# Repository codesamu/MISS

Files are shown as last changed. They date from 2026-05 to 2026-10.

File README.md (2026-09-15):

<div align="center">

# 🗑️ MISS
**An AI-Powered Multi Item Sorting System**






*A Diploma Thesis by **Fronthaler** and **Glatz***

<p align="center">
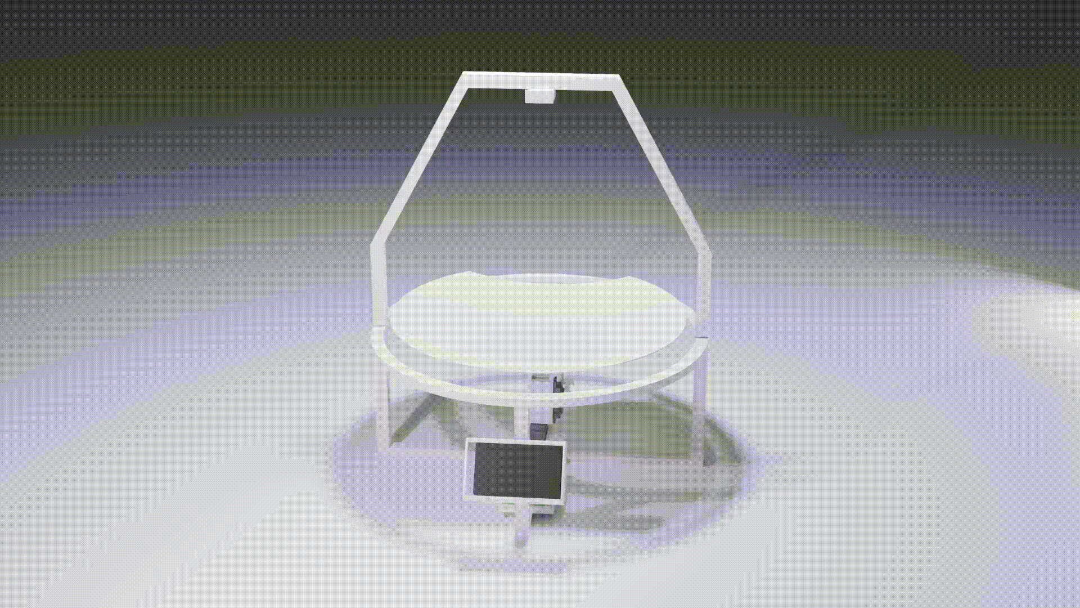
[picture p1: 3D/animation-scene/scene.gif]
MISS Sorting System Animation
  
</p>

</div>

---

## 📝 Overview
MISS (Multi Item Sorting System) is an intelligent waste sorting system designed to automate the process of recycling. By combining computer vision with custom hardware, the system identifies waste types and sorts them accordingly using servos.

## 🚀 Key Features
- **🤖 AI Detection**: Uses YOLO (You Only Look Once) to classify waste in real-time.
- **🖥️ Custom GUI**: A dedicated interface for monitoring camera feeds and system status.
- **⚙️ Hardware Control**: Custom PCB design and servo motor integration for physical sorting.
- **📦 3D Design**: Fully integrated mechanical structure designed for 3D printing.

## 📂 Project Structure
- `3D/`: CAD files, Blender scene, and print-ready STL/3MF files for the physical bin structure.
- `YOLO/`: YOLO model training and detection scripts.
- `capture-photos/`: Scripts for capturing training images from the camera.
- `display-cam-gui/`: Python-based GUI for the system display and camera feed.
- `pcb/`: PCB schematic and layout files for the electronics.
- `servo-test/`: Hardware testing scripts for the sorting mechanisms.
- `Doku-IMG/`: Diagrams and images used in the thesis documentation.

## 🛠️ Tech Stack
- **Languages**: Python
- **AI Framework**: Ultralytics YOLO
- **Hardware**: Custom PCBs, Servo Motors, Raspberry Pi, Camera Module
- **3D Design**: FreeCAD, Blender (for animation renders)

## 📄 Documentation
The complete diploma thesis is included as `Diplomarbeit.docx` in the repository root.

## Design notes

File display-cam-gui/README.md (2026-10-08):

# Live-Erkennung

Im Projektordner einmal einrichten (Systempakete fuer das Display mitverwenden):

```bash
python3 -m venv --system-site-packages .venv
.venv/bin/python -m pip install -r display-cam-gui/requirements.txt
```

Direkt starten:

```bash
.venv/bin/python display-cam-gui/live-detection.py
```

Oder im Dashboard **Live-Erkennung** antippen. Beenden mit dem roten
Touch-Button unten rechts oder Strg+C. Andere Kamera-Apps vorher beenden.

Das Programm zeigt den rpicam-vid-Kamerastream auf dem ST7796-LCD (480x320).
Es verarbeitet immer das neueste verfuegbare Bild und zeichnet Ergebnisse
auf genau dieses Bild. Die Bildrate haengt von der Inferenzzeit ab; waehrend
einer Vorhersage bleibt das zuletzt ausgewertete Bild sichtbar.
Das volle 4:3-Kamerabild bleibt mit schwarzen Raendern erhalten.
Die Kamera laeuft mit 30 FPS; die KI verarbeitet davon nur die jeweils neuesten
Bilder. Die FPS-Anzeige unten misst die Geschwindigkeit der Modellauswertung.

Ohne Argument erscheint zuerst eine **Modellauswahl auf dem Touchdisplay**.
Sie zeigt `YOLO/pet.pt` und die Detection-`best.pt` aus `YOLO/runs/`
beziehungsweise `runs/detect/`, neueste zuerst. Jeder Eintrag zeigt den Namen
des Trainingslaufs. Mit **Weiter/Zurueck** blaettern und den gewuenschten Lauf
antippen. **Abbrechen** kehrt ohne Kamerastart zurueck. Das gilt auch beim
Start aus dem Dashboard. Auf dem Raspberry Pi muessen die gewuenschten
Laufordner mit `train/weights/best.pt` vorhanden sein. Die alten Modelle unter
`runs/classify/` werden absichtlich nicht mehr geladen: Eine Bildklassifikation
kann keine Objektposition und damit keine Bounding Box liefern. Fehlt ein
trainierter Detektor, beendet sich die Anwendung mit einer klaren Meldung.

Bounding Boxes, Klassenname und Confidence werden direkt auf das ausgewertete
Kamerabild gezeichnet. Klassennamen werden aus dem Modell gelesen, etwa
`aluminum-can` und `plastic-bottle`; auch alte PET-Modelle funktionieren.
Jede Klasse hat eine eigene Farbe (die Palette wiederholt sich ab fuenf Klassen).
Mehrere Klassen koennen gleichzeitig erkannt werden. Der Status oben links
wird **pro Klasse getrennt** stabilisiert: Zwei Frames hintereinander muessen mindestens
60 % erreichen. Eine aktive Erkennung bleibt bis zu vier schwache Frames
erhalten; auch die Halteschwelle liegt bei 60 %. Dadurch
springt die Anzeige bei einzelnen unsicheren Frames nicht mehr sofort zwischen
erkannt und nicht erkannt. Ohne aktive Klasse steht dort **Kein Objekt erkannt**.
Mehrere erkannte Klassen erhalten eigene Statuszeilen. Ab fuenf Klassen werden
weitere zusammengefasst; Boxen werden weiterhin fuer alle Klassen gezeichnet. API:
[Ultralytics Predict](https://docs.ultralytics.com/modes/predict/).

Modelle auflisten bzw. einen Run explizit auswaehlen:

```bash
.venv/bin/python display-cam-gui/live-detection.py --list-models
.venv/bin/python display-cam-gui/live-detection.py --model YOLO/pet.pt
.venv/bin/python display-cam-gui/live-detection.py --model YOLO/runs/pet_jhp02naa/train/weights/best.pt
```

`--model` ueberspringt die Touch-Auswahl und akzeptiert auch mehrere Pfade, die nacheinander auf demselben Bild
ausgewertet werden. Das kostet entsprechend mehr Rechenzeit.
Mit `--conf 0.6` die Einschaltschwelle und mit `--keep-conf 0.35` die niedrigere
Halteschwelle ändern. `--confirm-frames` und `--release-frames` steuern die
zeitliche Entprellung. Mit `--imgsz 320` kann die Inferenzgröße verkleinert
werden (Standard: 640); das ist schneller, kann aber Erkennungsqualität kosten.
Fuer einen kurzen Hardwaretest: `--max-frames 10`.

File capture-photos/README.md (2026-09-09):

# Automatische Fotoaufnahme

Das Programm zeigt das aktuelle Kamerabild auf dem 480x320-Touchdisplay an und
speichert alle fuenf Sekunden ein Foto. Die Aufnahme endet, sobald auf dem
Display **STOP** gedrueckt wird.

## Start

Im Projektordner ausfuehren:

```bash
python3 glatz/main.py
```

Vor dem Start muss die bisherige Kamera-App beziehungsweise das Dashboard
vollstaendig beendet sein, da Kamera, Display und Touch nicht von zwei
Programmen gleichzeitig verwendet werden koennen.

Die JPEG-Bilder werden standardmaessig unter `glatz/photos/` abgelegt. Ihre
Dateinamen enthalten Datum und Uhrzeit, zum Beispiel
`muell_20260901_143012_123.jpg`.

Optional lassen sich Zielordner und Intervall aendern:

```bash
python3 glatz/main.py --output-dir /pfad/zu/fotos --interval 5
```

Die Kamera wird fest im 4:3-Modus 1296x972 betrieben. Bei der verbauten OV5647
verwendet dieser Modus den kompletten 2592x1944-Sensorbereich und damit das volle
Sichtfeld. Die Vorschau wird mit schwarzen Seitenraendern eingepasst, damit auch
auf dem 16:9-Bildbereich des Displays nichts abgeschnitten wird.

Das Programm verwendet die bereits im Projekt vorhandenen Display- und
Touch-Treiber aus `display-cam-gui/`. Labeling oder Klassifizierung findet nicht
statt.

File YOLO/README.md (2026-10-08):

# Plastikflaschen und Aludosen trainieren

## Neuen Datensatz wieder zusammenfuehren

Wenn der COCO-Export bereits in `dataset/train`, `dataset/valid` (oder `val`)
und `dataset/test` aufgeteilt ist, im Ordner `YOLO` ausfuehren:

```powershell
python merge_dataset.py
```

Das Programm kopiert alle Bilder nach `dataset/PET` und erstellt dort eine
gemeinsame `_annotations.coco.json`. Bild- und Markierungs-IDs werden eindeutig
neu vergeben; die Zuordnung der Markierungen zu ihren Bildern bleibt erhalten.
Dateinamen bekommen den bisherigen Split als Praefix, etwa `train_bild.jpg`.
Boxen, Klassen, Lizenzen und weitere Metadaten bleiben erhalten.

Der neue Export enthaelt 1741 Bilder und 4478 Markierungen fuer Plastikflaschen
(`plastic-bottle`) und Aludosen (` aluminum-can`). Der Zielordner heisst wie
bisher `PET`, enthaelt aber **beide Klassen**. Die urspruenglichen Teilmengen
werden nicht geloescht. Ein vorhandener Zielordner wird nicht ueberschrieben.
Das Skript benoetigt nur Python, keine zusaetzlichen Bibliotheken.

Andere Ordner lassen sich so angeben:

```powershell
python merge_dataset.py --source "pfad/zum/export" --output "pfad/zum/gesamt"
```

Die Zusammenfuehrung hebt die bisherige Trennung der Testdaten auf. Ein spaeterer
neuer Split ist deshalb eine neue Versuchsaufteilung.

## Training starten

Im Terminal im Ordner `YOLO` ausfuehren:

```powershell
python -m pip install -r requirements.txt
python train.py
```

Das Skript liest `dataset/PET/_annotations.coco.json`, wandelt die Boxen ins
YOLO-Format um und teilt die Bilder reproduzierbar in 80 % Training,
10 % Validierung und 10 % Test. Anschliessend trainiert es YOLO26n fuer
30 Epochen und wertet das beste Modell auf den Testbildern aus.
Beim ersten Training wird das vortrainierte Modell heruntergeladen.

Das fertige Modell liegt unter `YOLO/pet.pt` (wird beim naechsten Training
ersetzt). Jeder Aufruf legt einen eigenen Ordner unter `YOLO/runs/` fuer
Datenkopien und Ergebnisse an. Die Originaldaten bleiben erhalten.
Der Modellname `pet.pt` bleibt aus Kompatibilitaetsgruenden bestehen;
das neu trainierte Modell erkennt beide Klassen.

Optional:

```powershell
python train.py --epochs 50
python train.py --split-only
```

`--split-only` funktioniert auch ohne installierte Trainingsbibliotheken.

Ein Bild mit dem trainierten Modell pruefen:

```powershell
yolo predict model=pet.pt source="pfad/zum/bild.jpg" save=True
```

Training und Auswertung verwenden die [Ultralytics-API](https://docs.ultralytics.com/tasks/detect/).

## Dataset und Vorbereitung

Das zusammengefuehrte Dataset enthaelt 1741 Bilder und 4478 Markierungen.
Die Markierungen stehen im COCO-Format in `_annotations.coco.json`.
Das Training uebernimmt automatisch alle Klassen mit Markierungen und vergibt
fortlaufende YOLO-Klassen-IDs. Leerzeichen am Rand der Klassennamen werden entfernt:

| COCO-ID | YOLO-ID | Klasse |
| --- | --- | --- |
| 1 | 0 | `aluminum-can` (Aludose) |
| 2 | 1 | `plastic-bottle` (Plastikflasche) |

Die unbenutzte Oberkategorie `smartbin` wird nicht als Erkennungsklasse trainiert.

Eine COCO-Box beschreibt `x, y, Breite, Hoehe` in Pixeln, wobei `x, y` die
linke obere Ecke angeben. Eine YOLO-Labelzeile enthaelt dagegen:

```text
Klasse Mittelpunkt_X Mittelpunkt_Y Breite Hoehe
```

Alle vier Koordinaten werden durch die jeweilige Bildbreite bzw. Bildhoehe
geteilt. Sie liegen damit zwischen 0 und 1. Fuer jedes markierte Objekt entsteht
eine Zeile; Bilder ohne Markierung erhalten eine leere Labeldatei.

Die Bilder werden nach ID sortiert und mit Seed 42 gemischt. Beim aktuellen
Dataset entstehen 1392 Trainingsbilder, 174 Validierungsbilder und 175 Testbilder.
Der Rundungsrest geht in die Testmenge. Jedes Bild gehoert genau einer Menge an:

| Teilmenge | Verwendung |
| --- | --- |
| Training | Anpassung der Modellgewichte |
| Validierung | Kontrolle nach den Epochen und Auswahl des besten Modells |
| Test | Abschliessende Auswertung des besten Modells auf zurueckgehaltenen Bildern |

Bei unveraenderten Quelldaten bleibt die Aufteilung bei jedem Aufruf gleich.
Das Training selbst kann je nach Hardware und Bibliotheksversion leicht
unterschiedliche Ergebnisse liefern.

## Trainingseinstellungen

| Einstellung | Wert | Bedeutung |
| --- | --- | --- |
| Modell | `yolo26n.pt` | Kleines vortrainiertes Modell als Ausgangspunkt |
| Epochen | 30 | Angeforderte Durchlaeufe durch die Trainingsdaten; mit `--epochs` aenderbar |
| Bildgroesse | 640 | Zielgroesse fuer die Bildaufbereitung; Originaldateien bleiben unveraendert |
| Batch | 8 | Bilder pro Trainingsschritt |
| Workers | 0 | Laden der Daten im Hauptprozess, einfach unter Windows |
| Seed | 42 | Zufallsstartwert fuer Split und Training |
| Geraet | automatisch | Ultralytics waehlt das verfuegbare Geraet |

Weitere Einstellungen wie Optimierer, Lernrate, Datenaugmentation und vorzeitiges
Beenden verwenden die Standardwerte der installierten Ultralytics-Version.
Die konkret aufgeloesten Werte werden in `train/args.yaml` gespeichert.
Die tatsaechlich abgeschlossenen Epochen stehen in `train/results.csv`.
Auf der CPU kann das Training deutlich laenger dauern als auf einer GPU.

Nach dem Training wird `weights/best.pt` als `YOLO/pet.pt` kopiert und auf der
Testmenge ausgewertet. `best.pt` ist das anhand der Validierung ausgewaehlte
Modell; `last.pt` enthaelt den zuletzt gespeicherten Trainingsstand.

## Automatische Dokumentation

Jeder Lauf erhaelt unter `YOLO/runs/pet_.../` einen eigenen Ordner:

```text
pet_.../
  bericht.md           Zusammenfassung mit Einstellungen, Laufzeit und Metriken
  dataset/
    data.yaml          Dataset-Pfad, Teilmengen und Klassennamen
    images/            Bilder in train/, val/ und test/
    labels/            Passende YOLO-Labels in train/, val/ und test/
  train/
    args.yaml          Vollstaendige Trainingseinstellungen
    results.csv        Verluste und Metriken pro Epoche
    results.png        Diagramme zum Trainingsverlauf
    weights/
      best.pt          Bestes Modell nach Validierung
      last.pt          Zuletzt gespeicherter Trainingsstand
  test/                Diagramme und Beispielbilder der Testauswertung
```

Ultralytics erzeugt zusaetzlich unter anderem Konfusionsmatrizen, Kurven zur
Erkennungsqualitaet und Bilder mit eingezeichneten Vorhersagen. Die genauen
Dateinamen haengen von der installierten Version ab. `bericht.md` wird nach
erfolgreichem Abschluss der Testauswertung geschrieben. Bei `--split-only`
entsteht nur der vorbereitete Dataset-Ordner.

## Ergebnisse verstehen

| Metrik | Bedeutung |
| --- | --- |
| Precision | Welcher Anteil der erkannten Objekte tatsaechlich korrekt ist; hoch bedeutet wenige Fehlalarme |
| Recall | Welcher Anteil der markierten Objekte gefunden wird; hoch bedeutet wenige uebersehene Objekte |
| mAP50 | Erkennungsqualitaet bei mindestens 50 % Ueberlappung (IoU) zwischen vorhergesagter und echter Box |
| mAP50-95 | Mittlere Erkennungsqualitaet ueber IoU-Schwellen von 0,50 bis 0,95; bewertet die Genauigkeit der Boxen strenger |
| Trainings-/Validierungsverlust | Fehlerfunktion beim Lernen bzw. Pruefen; kleinere Werte sind meist besser |

Precision, Recall und mAP liegen zwischen 0 und 1; groessere Werte sind besser.
Sinkender Trainingsverlust bei schlechter werdender Validierung kann auf
Ueberanpassung hinweisen. Zusaetzlich immer einige Vorhersagebilder anschauen:
Werden Flaschen oder Dosen uebersehen, verwechselt, doppelt markiert oder andere Gegenstaende erkannt?

## Grenzen der Auswertung

Der einfache Split mischt einzelne Bilder. Sehr aehnliche Bilder aus derselben
Aufnahmeserie koennen dadurch in verschiedenen Teilmengen landen und Ergebnisse
zu gut erscheinen lassen. Fuer eine belastbare Beurteilung spaeter mit neuen
Aufnahmeserien, anderen Lichtverhaeltnissen und anderen Flaschen und Dosen testen.

Das Modell lernt die Klassen Plastikflasche und Aludose. Fuer den Einsatz im
Smartbin sind auch Testbilder mit anderem Muell und ohne diese Objekte sinnvoll,
um Fehlalarme zu messen.
Die Testmenge sollte fuer die abschliessende Beurteilung dienen; Einstellungen
anhand der Validierung auswaehlen.

Fuer einen nachvollziehbaren Versuch den gesamten Laufordner zusammen mit der
verwendeten Version von `train.py` und den Originaldaten aufbewahren.

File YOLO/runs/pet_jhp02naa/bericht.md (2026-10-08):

# Trainingsbericht Smartbin

- Ultralytics-Version: 8.4.146
- Startmodell: yolo26n.pt (vortrainiert)
- Aufgabe: Objekterkennung
- Klassen: 0 = aluminum-can, 1 = plastic-bottle
- Angeforderte Epochen: 30
- Bildgroesse: 640; Batch: 8; Workers: 0; Seed: 42
- Aufteilung: 80 % Training / 10 % Validierung / 10 % Test
- Laufzeit inklusive Test: 25.6 Minuten
- Dataset-Konfiguration: C:\Users\maxig\OneDrive\Desktop\smartbin\MISS\YOLO\runs\pet_jhp02naa\dataset\data.yaml
- Bestes Modell dieses Laufs: C:\Users\maxig\OneDrive\Desktop\smartbin\MISS\YOLO\runs\pet_jhp02naa\train\weights\best.pt
- Modellkopie: C:\Users\maxig\OneDrive\Desktop\smartbin\MISS\YOLO\pet.pt

## Bilder pro Teilmenge

- train: 1392
- val: 174
- test: 175

## Validierung

| Metrik | Wert |
| --- | ---: |
| metrics/precision(B) | 0.9572 |
| metrics/recall(B) | 0.9214 |
| metrics/mAP50(B) | 0.9708 |
| metrics/mAP50-95(B) | 0.8477 |
| fitness | 0.8477 |

## Test

| Metrik | Wert |
| --- | ---: |
| metrics/precision(B) | 0.9346 |
| metrics/recall(B) | 0.9260 |
| metrics/mAP50(B) | 0.9615 |
| metrics/mAP50-95(B) | 0.8393 |
| fitness | 0.8393 |

## Detaildateien

- `train/args.yaml`: alle tatsaechlich verwendeten Trainingseinstellungen
- `train/results.csv`: Metriken und Verluste pro abgeschlossener Epoche
- `train/results.png`: Verlauf des Trainings
- `train/`: weitere Diagramme und Beispielbilder der Validierung
- `test/`: Diagramme und Beispielbilder der Testauswertung

Erklaerungen und Grenzen der Auswertung stehen in `YOLO/README.md`.

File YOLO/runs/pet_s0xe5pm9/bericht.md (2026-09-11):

# Trainingsbericht PET

- Ultralytics-Version: 8.4.144
- Startmodell: yolo26n.pt (vortrainiert)
- Aufgabe: Objekterkennung; Klasse 0 = PET
- Angeforderte Epochen: 30
- Bildgroesse: 640; Batch: 8; Workers: 0; Seed: 42
- Aufteilung: 80 % Training / 10 % Validierung / 10 % Test
- Laufzeit inklusive Test: 77.4 Minuten
- Dataset-Konfiguration: C:\Users\maxig\OneDrive\Desktop\smartbin\MISS\YOLO\runs\pet_s0xe5pm9\dataset\data.yaml
- Bestes Modell dieses Laufs: C:\Users\maxig\OneDrive\Desktop\smartbin\MISS\YOLO\runs\pet_s0xe5pm9\train\weights\best.pt
- Modellkopie: C:\Users\maxig\OneDrive\Desktop\smartbin\MISS\YOLO\pet.pt

## Bilder pro Teilmenge

- train: 595
- val: 74
- test: 75

## Validierung

| Metrik | Wert |
| --- | ---: |
| metrics/precision(B) | 0.9096 |
| metrics/recall(B) | 0.8746 |
| metrics/mAP50(B) | 0.9559 |
| metrics/mAP50-95(B) | 0.7227 |
| fitness | 0.7227 |

## Test

| Metrik | Wert |
| --- | ---: |
| metrics/precision(B) | 0.8623 |
| metrics/recall(B) | 0.8939 |
| metrics/mAP50(B) | 0.9513 |
| metrics/mAP50-95(B) | 0.7088 |
| fitness | 0.7088 |

## Detaildateien

- `train/args.yaml`: alle tatsaechlich verwendeten Trainingseinstellungen
- `train/results.csv`: Metriken und Verluste pro abgeschlossener Epoche
- `train/results.png`: Verlauf des Trainings
- `train/`: weitere Diagramme und Beispielbilder der Validierung
- `test/`: Diagramme und Beispielbilder der Testauswertung

Erklaerungen und Grenzen der Auswertung stehen in `YOLO/README.md`.

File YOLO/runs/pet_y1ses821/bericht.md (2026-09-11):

# Trainingsbericht PET

- Ultralytics-Version: 8.4.146
- Startmodell: yolo26n.pt (vortrainiert)
- Aufgabe: Objekterkennung; Klasse 0 = PET
- Angeforderte Epochen: 30
- Bildgroesse: 640; Batch: 8; Workers: 0; Seed: 42
- Aufteilung: 80 % Training / 10 % Validierung / 10 % Test
- Laufzeit inklusive Test: 14.9 Minuten
- Dataset-Konfiguration: C:\Users\maxig\OneDrive\Desktop\smartbin\MISS\YOLO\runs\pet_y1ses821\dataset\data.yaml
- Bestes Modell dieses Laufs: C:\Users\maxig\OneDrive\Desktop\smartbin\MISS\YOLO\runs\pet_y1ses821\train\weights\best.pt
- Modellkopie: C:\Users\maxig\OneDrive\Desktop\smartbin\MISS\YOLO\pet.pt

## Bilder pro Teilmenge

- train: 595
- val: 74
- test: 75

## Validierung

| Metrik | Wert |
| --- | ---: |
| metrics/precision(B) | 0.9109 |
| metrics/recall(B) | 0.8869 |
| metrics/mAP50(B) | 0.9572 |
| metrics/mAP50-95(B) | 0.7236 |
| fitness | 0.7236 |

## Test

| Metrik | Wert |
| --- | ---: |
| metrics/precision(B) | 0.8858 |
| metrics/recall(B) | 0.8575 |
| metrics/mAP50(B) | 0.9467 |
| metrics/mAP50-95(B) | 0.7031 |
| fitness | 0.7031 |

## Detaildateien

- `train/args.yaml`: alle tatsaechlich verwendeten Trainingseinstellungen
- `train/results.csv`: Metriken und Verluste pro abgeschlossener Epoche
- `train/results.png`: Verlauf des Trainings
- `train/`: weitere Diagramme und Beispielbilder der Validierung
- `test/`: Diagramme und Beispielbilder der Testauswertung

Erklaerungen und Grenzen der Auswertung stehen in `YOLO/README.md`.

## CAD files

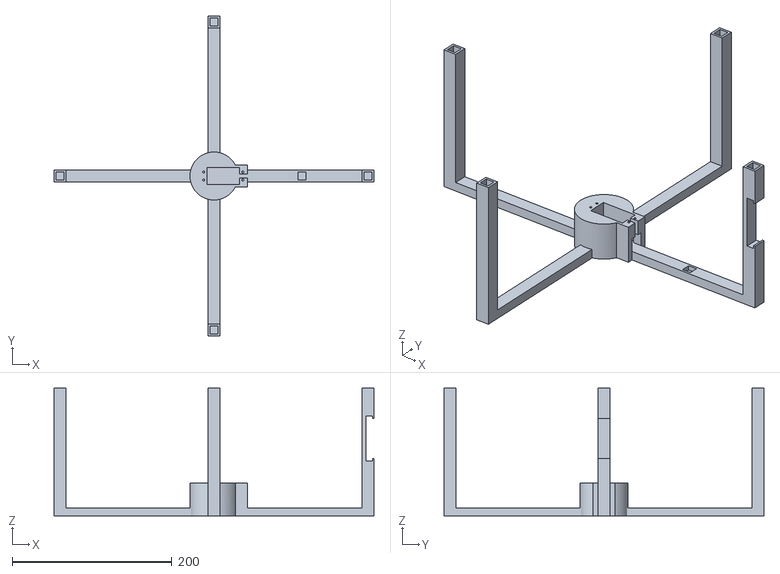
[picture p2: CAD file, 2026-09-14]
3D/bin-base-base.stl
400.0 x 400.0 x 160.0

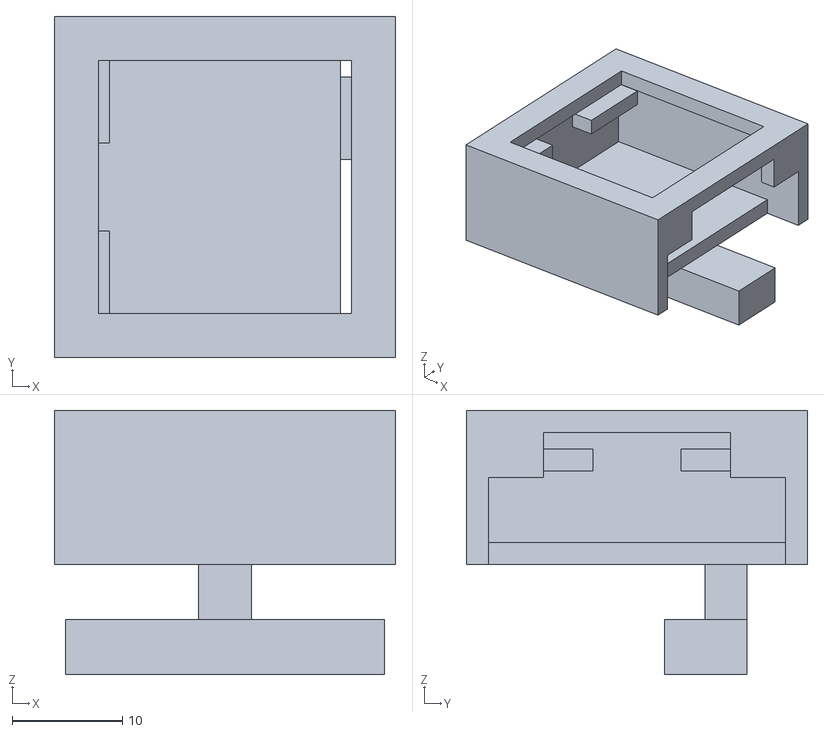
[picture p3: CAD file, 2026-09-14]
3D/bin-camera-mount.stl
31.0 x 31.0 x 24.0

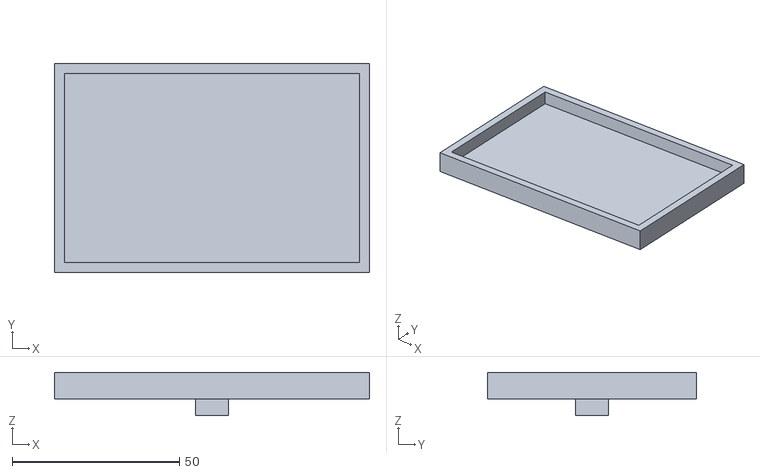
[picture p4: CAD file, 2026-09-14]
3D/bin-rpi-mnt.stl
94.2 x 62.5 x 13.0

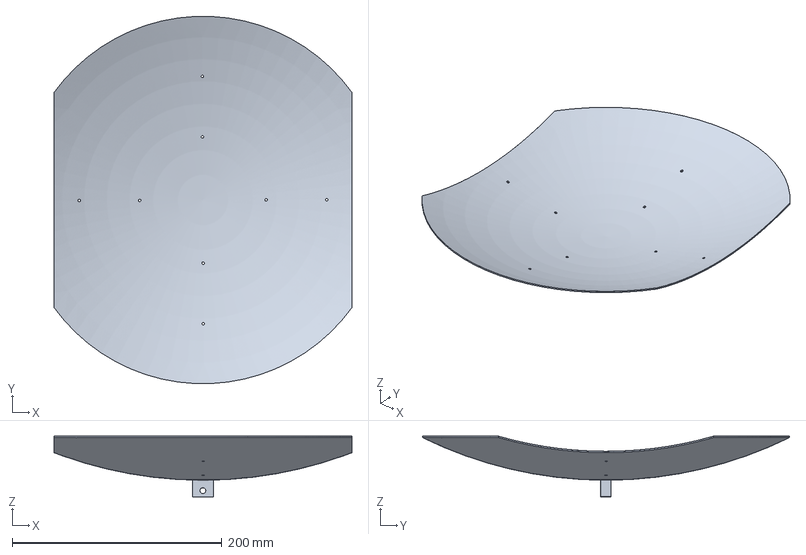
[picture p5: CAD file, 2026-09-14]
3D/bin-plate.3mf
284.2 x 350.1 x 57.9 mm

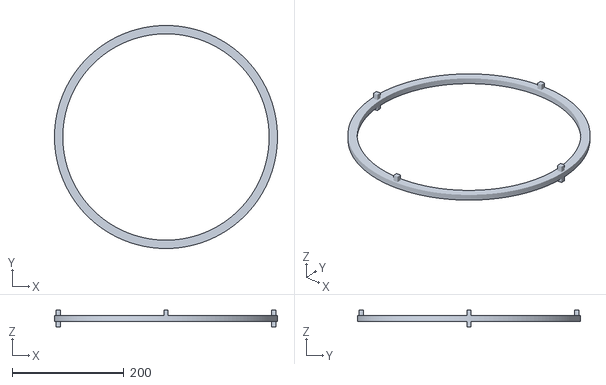
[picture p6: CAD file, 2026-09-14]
3D/bin-ring.stl
400.0 x 400.0 x 30.0

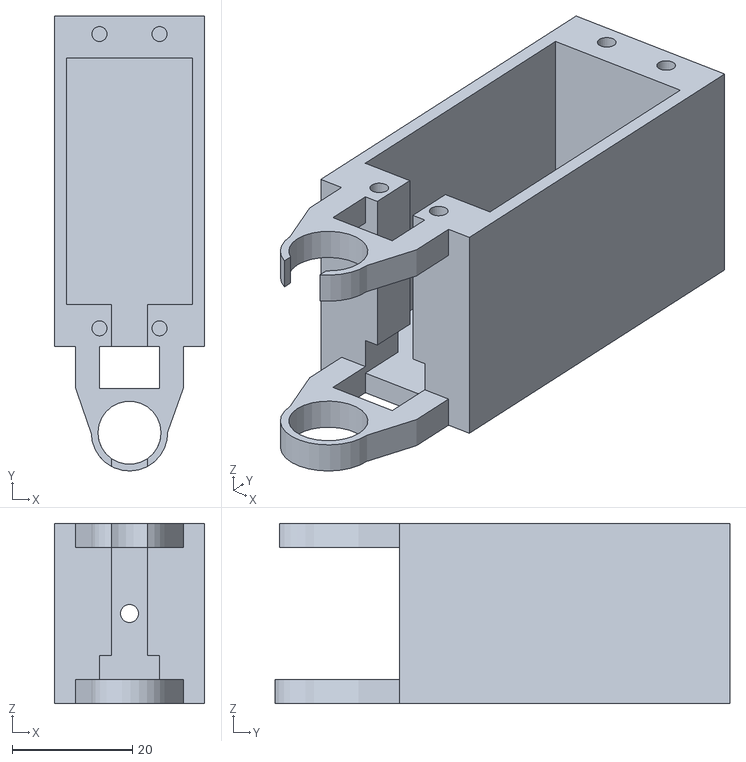
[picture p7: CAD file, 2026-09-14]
3D/bin-servo-case.stl
25.0 x 75.7 x 30.0

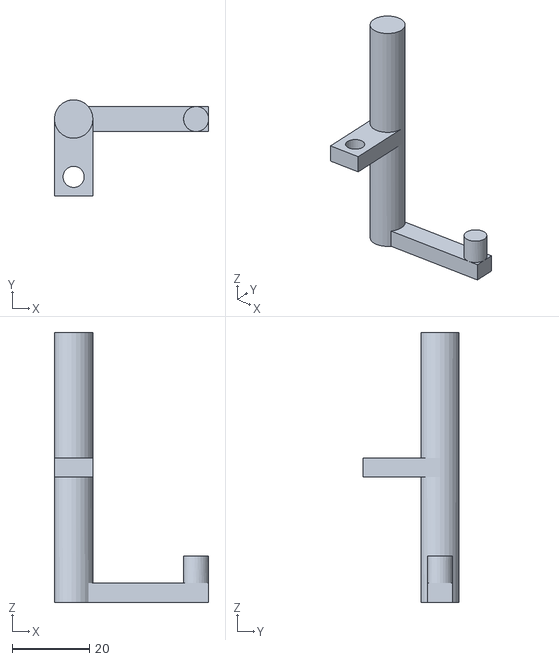
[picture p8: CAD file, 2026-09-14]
3D/bin-End-pushrod.stl
40.0 x 25.0 x 70.0

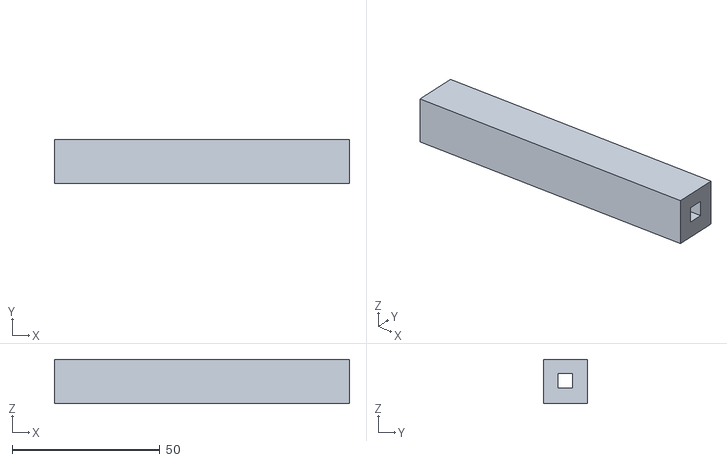
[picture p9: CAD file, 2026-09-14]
3D/bin-height adapter.stl
100.0 x 15.0 x 15.0

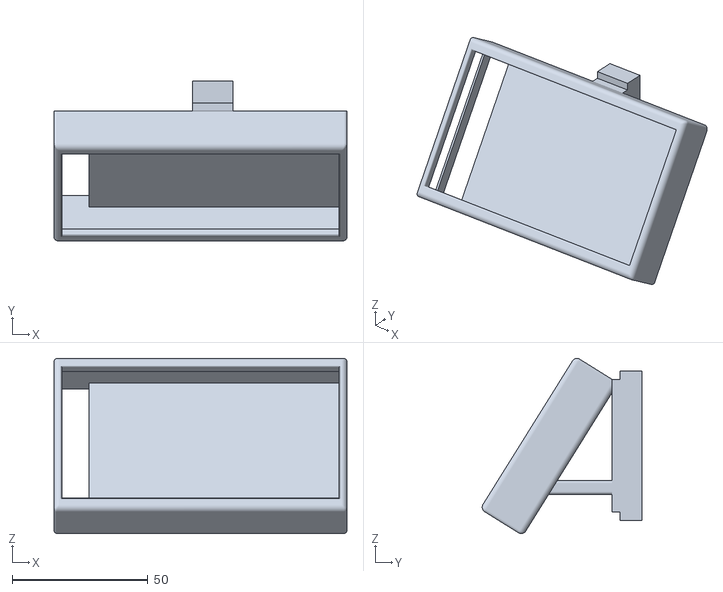
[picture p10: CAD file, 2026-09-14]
3D/bin-display-mnt.stl
108.0 x 58.8 x 64.5

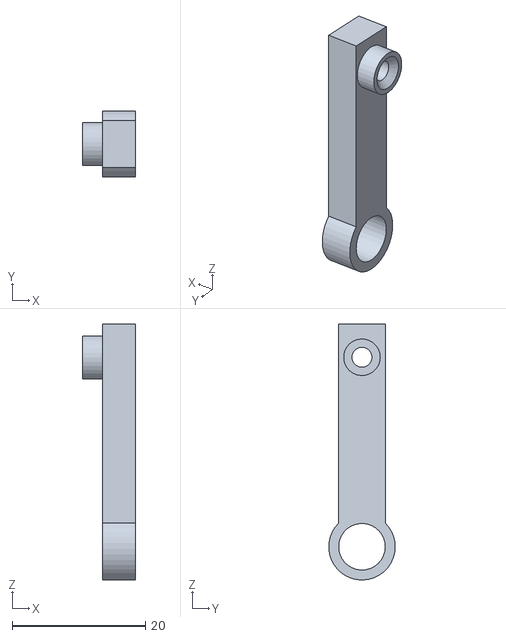
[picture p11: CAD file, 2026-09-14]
3D/bin-Servo-pushrod.stl
8.00 x 9.99 x 38.5

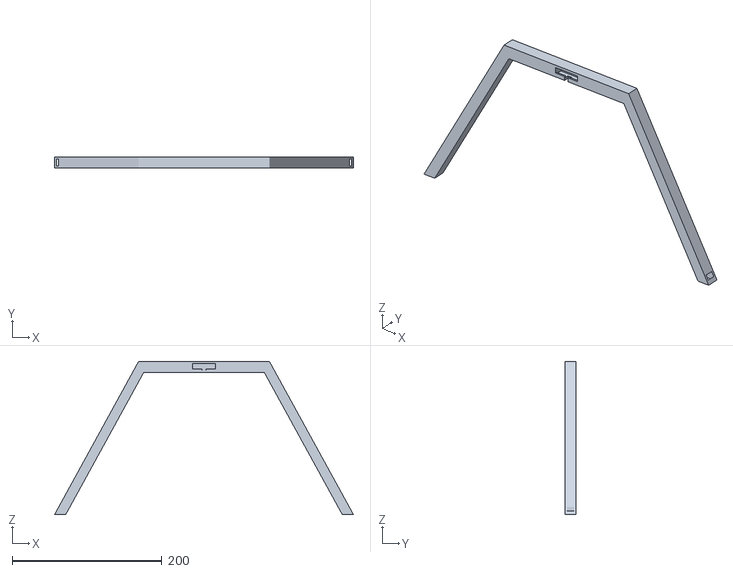
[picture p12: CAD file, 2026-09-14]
3D/bin-camera-rig.stl
400.0 x 15.0 x 205.0

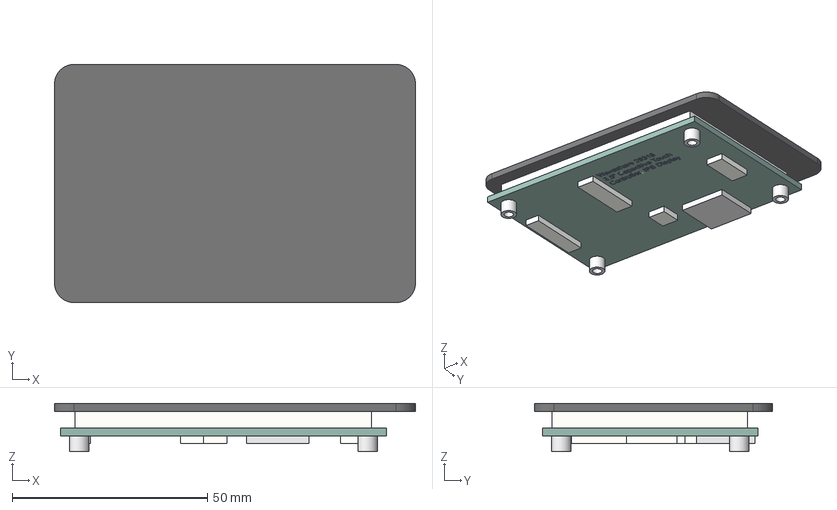
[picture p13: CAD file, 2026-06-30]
3D/Waveshare 3.5 Capacitive Touchscreen v1.step
92.4 x 61.0 x 12.3 mm

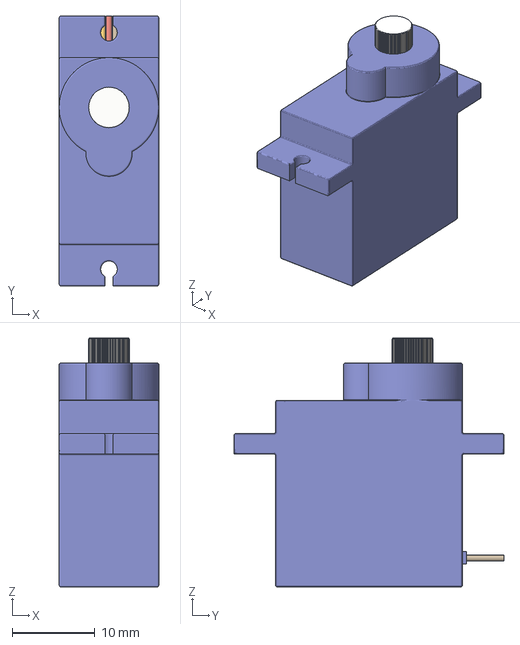
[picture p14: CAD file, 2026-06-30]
3D/servo.3mf
12.0 x 32.5 x 30.0 mm

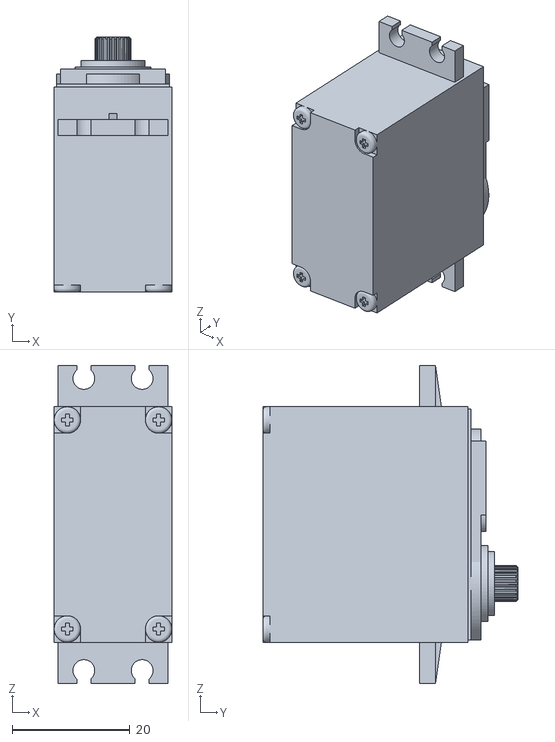
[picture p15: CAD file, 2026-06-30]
3D/Standard-Servo.stl
20.0 x 43.3 x 54.0

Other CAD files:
3D/Servo-assembly.FCStd
3D/bin-base-multipart.FCStd
3D/Pi Camera Module v3 Wide Angle.STL
3D/bin-pushrod-plate-locker.3mf
3D/bin-Middle-pushrod.stl
3D/bin-lock-pushrod.3mf
3D/bin-middle-pushrod.3mf

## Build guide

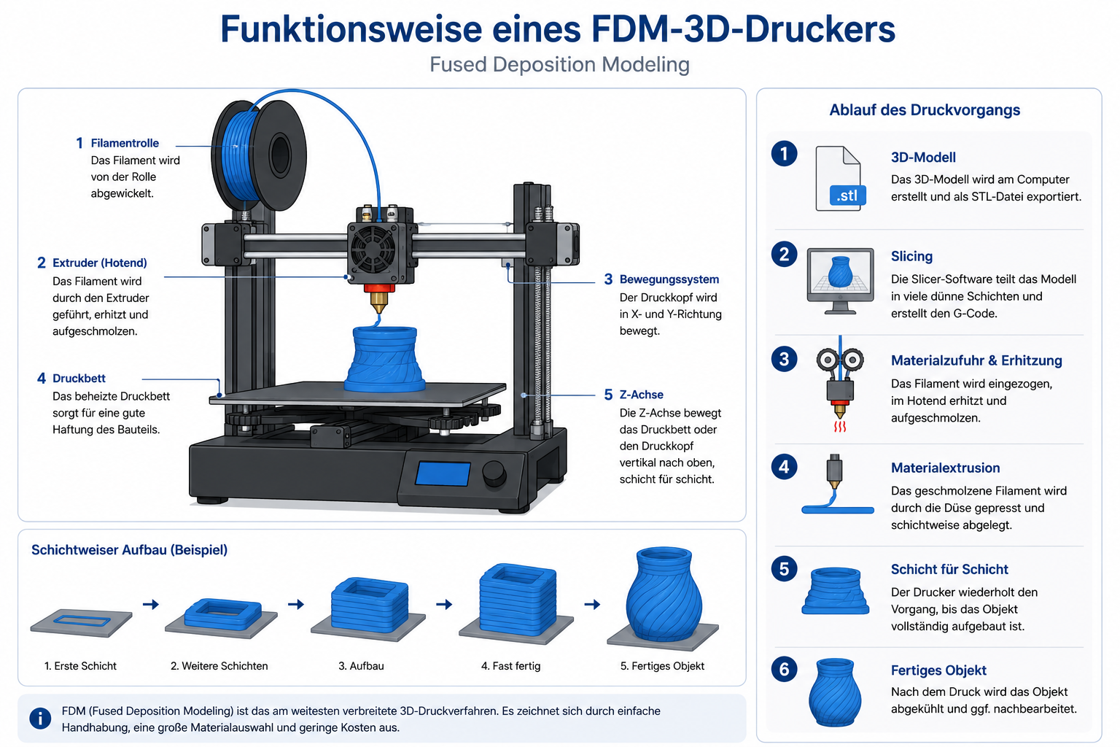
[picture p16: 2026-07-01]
Doku-IMG/Ablauf-Printer.png

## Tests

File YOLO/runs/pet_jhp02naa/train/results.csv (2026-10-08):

epoch | time | train/box_loss | train/cls_loss | train/l1_loss | metrics/precision(B) | metrics/recall(B) | metrics/mAP50(B) | metrics/mAP50-95(B) | val/box_loss | val/cls_loss | val/l1_loss | lr/pg0 | lr/pg1 | lr/pg2
1 | 53.8402 | 1.13369 | 4.42154 | 0.00795 | 0.84659 | 0.83062 | 0.88684 | 0.69965 | 0.9101 | 3.85579 | 0.00733 | 0.000552473 | 0.000552473 | 0.000552473
2 | 104.192 | 1.12888 | 2.84067 | 0.00797 | 0.90536 | 0.83577 | 0.90811 | 0.73313 | 0.93185 | 2.36951 | 0.00771 | 0.00107157 | 0.00107157 | 0.00107157
3 | 155.059 | 1.13244 | 2.01026 | 0.00807 | 0.92689 | 0.88582 | 0.92808 | 0.74406 | 0.97367 | 1.58719 | 0.00812 | 0.001554 | 0.001554 | 0.001554
4 | 205.353 | 1.15407 | 1.5237 | 0.0083 | 0.93639 | 0.89128 | 0.93872 | 0.76446 | 0.98338 | 1.26327 | 0.00807 | 0.00150197 | 0.00150197 | 0.00150197
5 | 256.768 | 1.13237 | 1.25299 | 0.00786 | 0.9663 | 0.89235 | 0.94156 | 0.74944 | 0.91979 | 0.97619 | 0.00721 | 0.00144696 | 0.00144696 | 0.00144696
6 | 309.227 | 1.06355 | 1.09111 | 0.00764 | 0.96107 | 0.87912 | 0.94173 | 0.78956 | 0.90427 | 0.80696 | 0.00708 | 0.00139195 | 0.00139195 | 0.00139195
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

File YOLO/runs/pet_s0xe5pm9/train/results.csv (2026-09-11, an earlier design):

epoch | time | train/box_loss | train/cls_loss | train/l1_loss | metrics/precision(B) | metrics/recall(B) | metrics/mAP50(B) | metrics/mAP50-95(B) | val/box_loss | val/cls_loss | val/l1_loss | lr/pg0 | lr/pg1 | lr/pg2
1 | 164.479 | 1.37191 | 3.50892 | 0.0089 | 0.87428 | 0.59544 | 0.78783 | 0.52094 | 1.08101 | 3.72489 | 0.00848 | 0.000657778 | 0.000657778 | 0.000657778
2 | 324.931 | 1.33791 | 2.61974 | 0.00862 | 0.8708 | 0.79511 | 0.91149 | 0.57795 | 1.2007 | 2.49358 | 0.00926 | 0.00128074 | 0.00128074 | 0.00128074
3 | 481.41 | 1.33498 | 2.20225 | 0.00866 | 0.90858 | 0.79021 | 0.90794 | 0.56473 | 1.17754 | 2.13217 | 0.00908 | 0.0018597 | 0.0018597 | 0.0018597
4 | 648.992 | 1.31403 | 1.84024 | 0.00848 | 0.94401 | 0.81346 | 0.93819 | 0.60093 | 1.19032 | 1.61098 | 0.00944 | 0.001802 | 0.001802 | 0.001802
5 | 805.882 | 1.29462 | 1.62312 | 0.0085 | 0.88827 | 0.85094 | 0.92728 | 0.62986 | 1.14005 | 1.53195 | 0.00872 | 0.001736 | 0.001736 | 0.001736
6 | 954.552 | 1.29579 | 1.45768 | 0.00844 | 0.9311 | 0.79817 | 0.91913 | 0.62109 | 1.203 | 1.18402 | 0.00919 | 0.00167 | 0.00167 | 0.00167
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

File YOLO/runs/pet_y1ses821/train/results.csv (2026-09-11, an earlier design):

epoch | time | train/box_loss | train/cls_loss | train/l1_loss | metrics/precision(B) | metrics/recall(B) | metrics/mAP50(B) | metrics/mAP50-95(B) | val/box_loss | val/cls_loss | val/l1_loss | lr/pg0 | lr/pg1 | lr/pg2
1 | 32.1941 | 1.39782 | 3.52128 | 0.00906 | 0.90267 | 0.53887 | 0.71928 | 0.47531 | 1.10223 | 3.78 | 0.0088 | 0.000657778 | 0.000657778 | 0.000657778
2 | 60.928 | 1.3114 | 2.67067 | 0.00834 | 0.89428 | 0.76147 | 0.87701 | 0.56049 | 1.14883 | 2.59906 | 0.00892 | 0.00128074 | 0.00128074 | 0.00128074
3 | 91.6962 | 1.31124 | 2.21281 | 0.0084 | 0.91167 | 0.78903 | 0.89653 | 0.56008 | 1.19355 | 2.1853 | 0.00918 | 0.0018597 | 0.0018597 | 0.0018597
4 | 122.136 | 1.34133 | 1.84961 | 0.0087 | 0.92267 | 0.82569 | 0.90833 | 0.58617 | 1.27784 | 1.69701 | 0.01081 | 0.001802 | 0.001802 | 0.001802
5 | 153.53 | 1.32824 | 1.62815 | 0.00881 | 0.91405 | 0.84404 | 0.93621 | 0.61432 | 1.16202 | 1.41452 | 0.00873 | 0.001736 | 0.001736 | 0.001736
6 | 184.761 | 1.29231 | 1.47906 | 0.00837 | 0.91507 | 0.81346 | 0.92329 | 0.62944 | 1.14256 | 1.26958 | 0.00896 | 0.00167 | 0.00167 | 0.00167
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

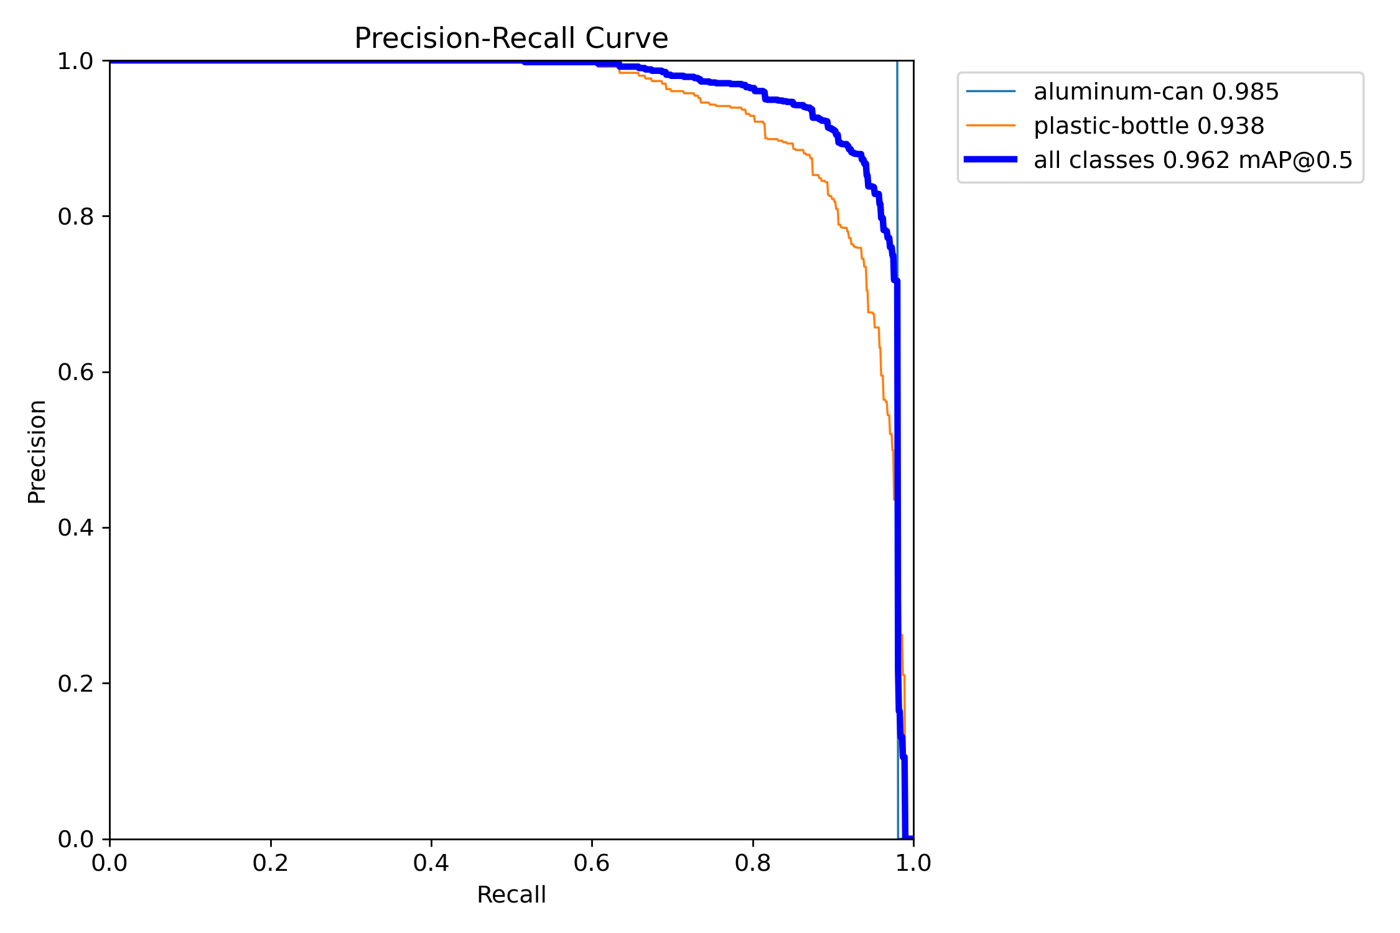
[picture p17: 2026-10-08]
YOLO/runs/pet_jhp02naa/test/BoxPR_curve.png

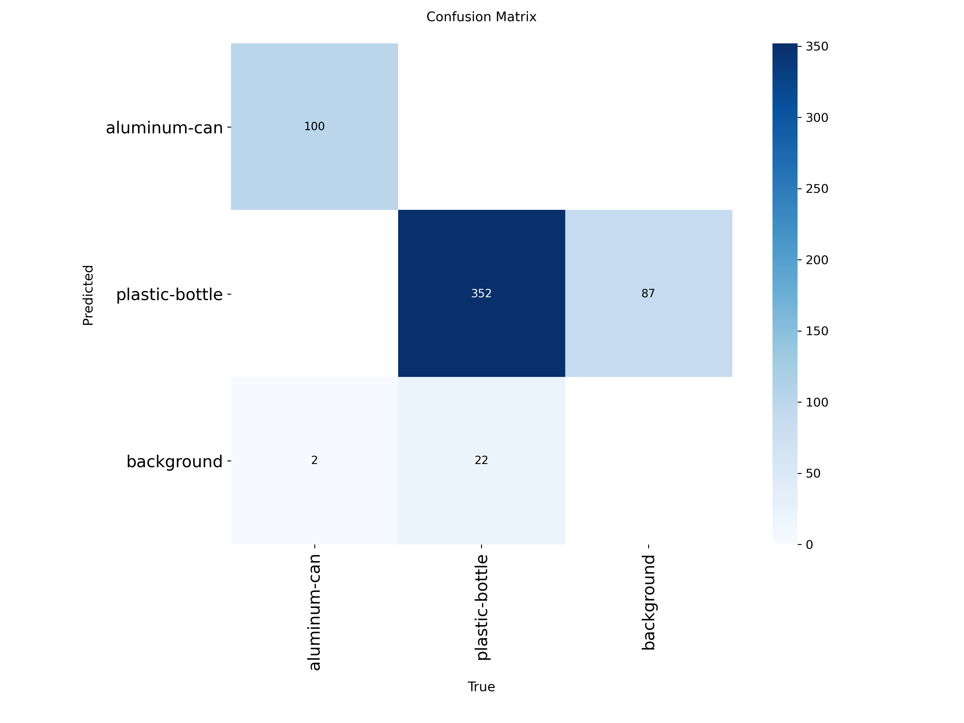
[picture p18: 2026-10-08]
YOLO/runs/pet_jhp02naa/test/confusion_matrix.png

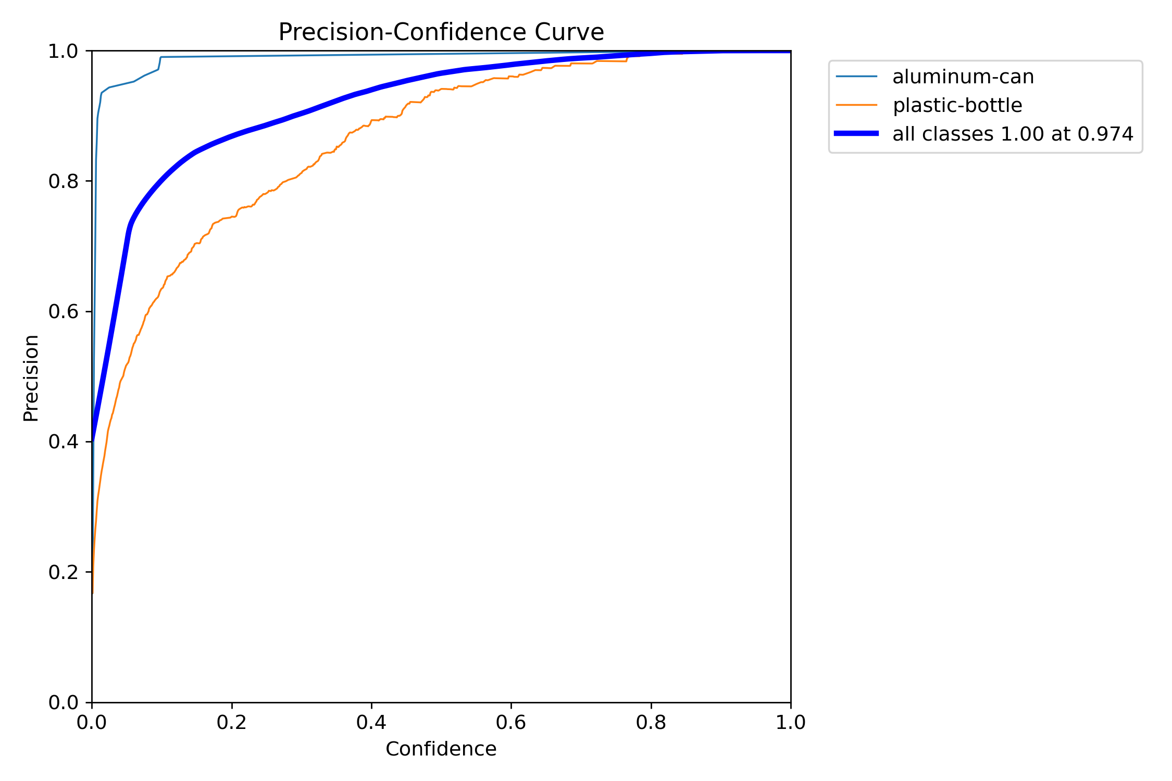
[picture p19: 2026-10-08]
YOLO/runs/pet_jhp02naa/test/BoxP_curve.png

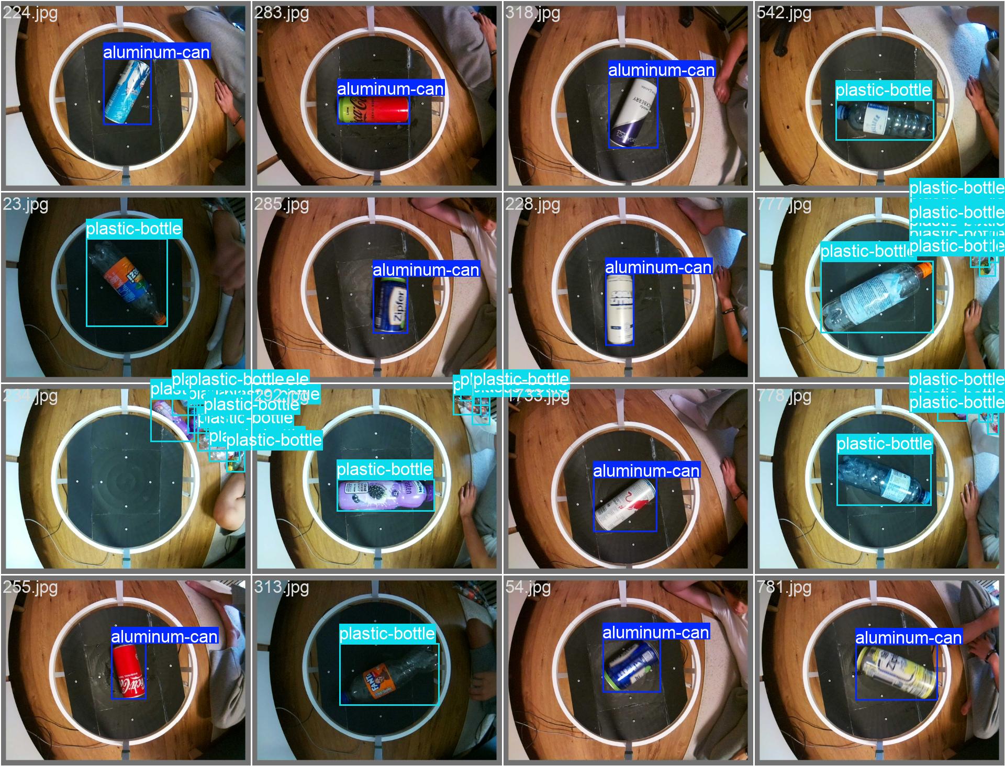
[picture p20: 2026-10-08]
YOLO/runs/pet_jhp02naa/test/val_batch2_labels.jpg

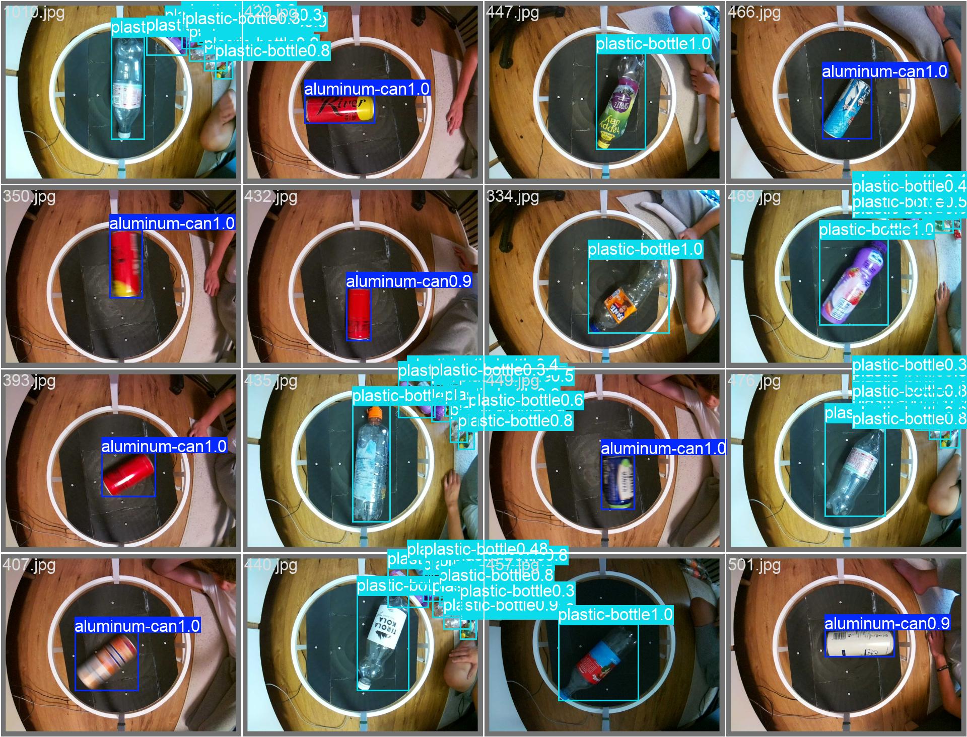
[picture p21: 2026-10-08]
YOLO/runs/pet_jhp02naa/test/val_batch0_pred.jpg

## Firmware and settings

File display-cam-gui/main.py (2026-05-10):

#!/usr/bin/python
# -*- coding: UTF-8 -*-

import io
import json
import queue
import shutil
import sys
import threading
import time
import subprocess
from datetime import datetime
from pathlib import Path

from PIL import Image, ImageDraw, ImageFont, ImageEnhance, ImageFilter

import st7796
import ft6336u


# ========================================
# Konfiguration
# ========================================

APP_DIR       = Path(__file__).resolve().parent
DATA_DIR      = APP_DIR / "dataset"
SETTINGS_FILE = APP_DIR / "settings.json"

# LCD (Querformat / Landscape)
LCD_WIDTH  = 480
LCD_HEIGHT = 320
HEADER_H   = 46

TOUCH_TIMEOUT = 0.05

# Fonts
FONT_PATH      = "/usr/share/fonts/truetype/dejavu/DejaVuSans.ttf"
FONT_PATH_BOLD = "/usr/share/fonts/truetype/dejavu/DejaVuSans-Bold.ttf"
FONT_LARGE  = ImageFont.truetype(FONT_PATH_BOLD, 24)
FONT_MEDIUM = ImageFont.truetype(FONT_PATH,      18)
FONT_SMALL  = ImageFont.truetype(FONT_PATH,      13)

# Farben
C_BG      = (18,  18,  18)
C_SURFACE = (35,  35,  45)
C_PRIMARY = (41,  98, 255)
C_SUCCESS = (30, 190,  90)
C_DANGER  = (220,  50,  50)
C_MUTED   = (120, 120, 135)
C_WHITE   = (255, 255, 255)
C_HEADER  = (25,  25,  40)

# Kategorien
LABELS = [
    ("Plastik",   "plastik"),
    ("Glas",      "glas"),
    ("Metall",    "metall"),
    ("Papier",    "papier"),
    ("Bio",       "bio"),
    ("Restmuell", "restmuell"),
    ("Elektro",   "elektro"),
    ("Textil",    "textil"),
    ("Sonstiges", "sonstiges"),
]


# ========================================
# UI-Hilfsfunktionen
# ========================================

def new_screen(bg=C_BG):
    """Neue leere Bildschirmfläche (480x320 Querformat)"""
    return Image.new('RGB', (LCD_WIDTH, LCD_HEIGHT), color=bg)


def draw_header(image, title):
    """Header-Leiste mit Trennlinie und zentriertem Titel"""
    draw = ImageDraw.Draw(image)
    draw.rectangle([0, 0, LCD_WIDTH, HEADER_H], fill=C_HEADER)
    draw.rectangle([0, HEADER_H, LCD_WIDTH, HEADER_H + 2], fill=C_PRIMARY)
    bbox = draw.textbbox((0, 0), title, font=FONT_LARGE)
    tx = (LCD_WIDTH - (bbox[2] - bbox[0])) // 2
    ty = (HEADER_H - (bbox[3] - bbox[1])) // 2
    draw.text((tx, ty), title, font=FONT_LARGE, fill=C_WHITE)


def draw_rounded_rect(draw, x, y, w, h, radius, fill, outline=None):
    """Rechteck mit abgerundeten Ecken"""
    draw.rectangle([x + radius, y, x + w - radius, y + h], fill=fill)
    draw.rectangle([x, y + radius, x + w, y + h - radius], fill=fill)
    draw.ellipse([x, y, x + 2*radius, y + 2*radius], fill=fill)
    draw.ellipse([x + w - 2*radius, y, x + w, y + 2*radius], fill=fill)
    draw.ellipse([x, y + h - 2*radius, x + 2*radius, y + h], fill=fill)
    draw.ellipse([x + w - 2*radius, y + h - 2*radius, x + w, y + h], fill=fill)
    if outline:
        draw.arc([x, y, x + 2*radius, y + 2*radius], 180, 270, fill=outline)
        draw.arc([x + w - 2*radius, y, x + w, y + 2*radius], 270, 360, fill=outline)
        draw.arc([x, y + h - 2*radius, x + 2*radius, y + h], 90, 180, fill=outline)
        draw.arc([x + w - 2*radius, y + h - 2*radius, x + w, y + h], 0, 90, fill=outline)
        draw.line([x + radius, y, x + w - radius, y], fill=outline)
        draw.line([x + radius, y + h, x + w - radius, y + h], fill=outline)
        draw.line([x, y + radius, x, y + h - radius], fill=outline)
        draw.line([x + w, y + radius, x + w, y + h - radius], fill=outline)


class TouchButton:
    """Touch-Button mit abgerundeten Ecken und zentriertem Text"""
    def __init__(self, x, y, w, h, text, bg=C_PRIMARY, fg=C_WHITE, font=None, radius=10):
        self.x, self.y, self.w, self.h = x, y, w, h
        self.text = text
        self.bg   = bg
        self.fg   = fg
        self.font = font or FONT_MEDIUM
        self.radius = radius

    def is_touched(self, tx, ty):
        return self.x <= tx <= self.x + self.w and self.y <= ty <= self.y + self.h

    def draw(self, image):
        draw = ImageDraw.Draw(image)
        draw_rounded_rect(draw, self.x, self.y, self.w, self.h, self.radius, self.bg)
        bbox = draw.textbbox((0, 0), self.text, font=self.font)
        tw = bbox[2] - bbox[0]
        th = bbox[3] - bbox[1]
        draw.text(
            (self.x + (self.w - tw) // 2, self.y + (self.h - th) // 2),
            self.text, font=self.font, fill=self.fg
        )


def ensure_data_dir():
    """Verzeichnisse für alle Kategorien anlegen"""
    for _, label_id in LABELS:
        (DATA_DIR / label_id).mkdir(parents=True, exist_ok=True)


def capture_rpicam(path, width=480, height=274, timeout_ms=500):
    """Einzelfoto mit rpicam-still aufnehmen"""
    subprocess.run(
        ['rpicam-still', '-o', str(path),
         '--width', str(width), '--height', str(height),
         '-n', '--timeout', str(timeout_ms)],
        check=False, timeout=15
    )


# ========================================
# Hauptanwendung
# ========================================

class SmartBinApp:
    def __init__(self):
        print("Initialisiere SmartBin (Querformat 480x320)...")
        try:
            self.lcd   = st7796.st7796()
            self.touch = ft6336u.ft6336u()
        except Exception as e:
            print(f"Hardware-Fehler: {e}")
            sys.exit(1)

        self.temp_path     = APP_DIR / "temp_preview.jpg"
        self.captured_path = APP_DIR / "temp_captured.jpg"
        self.state         = "main_menu"
        self.selected_idx  = None

        # Bildverarbeitungs-Einstellungen (Defaults)
        self.zoom        = 1.0
        self.center_x    = 0.0
        self.center_y    = 0.0
        self.brightness  = 0
        self.contrast    = 1.0
        self.saturation  = 1.0
        self.mirror      = False
        self.freeze      = False
        self.filter_mode = "normal"

        ensure_data_dir()
        self.load_settings()
        self.lcd.clear()
        print("Bereit.")

    # --------------------------------------------------
    # Touch – Querformat-Koordinatentransformation
    # Portrait-Touch: x=0..319, y=0..479
    # 90° CW Rotation: landscape_x = portrait_y
    #                  landscape_y = 319 - portrait_x
    # --------------------------------------------------
    def _get_touch(self):
        """Gibt (x, y) in Querformat-Koordinaten zurück, oder None"""
        self.touch.read_touch_data()
        result = self.touch.get_touch_xy()
        if result is None:
            return None
        point, coords = result
        if point != 0 and coords:
            px = coords[0]['x']   # Portrait x (0..319)
            py = coords[0]['y']   # Portrait y (0..479)
            # 90° CW: portrait top → landscape right
            lx = 479 - py         # Landscape x (0..479)
            ly = 319 - px         # Landscape y (0..319)
            return lx, ly
        return None

    def _wait_for_buttons(self, buttons):
        """Blockiert bis ein Button berührt wird. Gibt Index zurück."""
        while True:
            xy = self._get_touch()
            if xy:
                for i, btn in enumerate(buttons):
                    if btn.is_touched(*xy):
                        return i
            time.sleep(TOUCH_TIMEOUT)

    # --------------------------------------------------
    # Einstellungen laden / speichern
    # --------------------------------------------------
    def load_settings(self):
        try:
            if SETTINGS_FILE.exists():
                data = json.loads(SETTINGS_FILE.read_text(encoding="utf-8"))
                self.zoom        = float(data.get("zoom",        self.zoom))
                self.center_x    = float(data.get("center_x",    self.center_x))
                self.center_y    = float(data.get("center_y",    self.center_y))
                self.brightness  = int(  data.get("brightness",  self.brightness))
                self.contrast    = float(data.get("contrast",    self.contrast))
                self.saturation  = float(data.get("saturation",  self.saturation))
                self.mirror      = bool( data.get("mirror",      self.mirror))
                self.freeze      = bool( data.get("freeze",      self.freeze))
                self.filter_mode = str(  data.get("filter_mode", self.filter_mode))
        except Exception as e:
            print(f"Einstellungen laden: {e}")

    def save_settings(self):
        try:
            SETTINGS_FILE.write_text(json.dumps({
                "zoom":        self.zoom,
                "center_x":    self.center_x,
                "center_y":    self.center_y,
                "brightness":  self.brightness,
                "contrast":    self.contrast,
                "saturation":  self.saturation,
                "mirror":      self.mirror,
                "freeze":      self.freeze,
                "filter_mode": self.filter_mode,
            }, indent=2), encoding="utf-8")
        except Exception as e:
            print(f"Einstellungen speichern: {e}")

    # --------------------------------------------------
    # Bildverarbeitung
    # --------------------------------------------------
    def _apply_settings(self, frame):
        """Wendet Zoom, Pan, Helligkeit, Kontrast, Saettigung, Filter und Spiegel an"""
        img = frame
        w, h = img.size

        # Zoom + Pan (Crop + Resize)
        zoom = max(1.0, float(self.zoom))
        if zoom > 1.0:
            nw = max(1, int(w / zoom))
            nh = max(1, int(h / zoom))
            max_ox = max(0, (w - nw) // 2)
            max_oy = max(0, (h - nh) // 2)
            ox = int(w / 2 - nw / 2 + self.center_x * max_ox)
            oy = int(h / 2 - nh / 2 + self.center_y * max_oy)
            ox = max(0, min(w - nw, ox))
            oy = max(0, min(h - nh, oy))
            img = img.crop((ox, oy, ox + nw, oy + nh)).resize((w, h), Image.BILINEAR)

        # Helligkeit
        b_fac = 1.0 + self.brightness / 100.0
        if abs(b_fac - 1.0) > 0.01:
            img = ImageEnhance.Brightness(img).enhance(max(0.05, b_fac))

        # Kontrast
        if abs(self.contrast - 1.0) > 0.01:
            img = ImageEnhance.Contrast(img).enhance(self.contrast)

        # Saettigung
        if abs(self.saturation - 1.0) > 0.01:
            img = ImageEnhance.Color(img).enhance(self.saturation)

        # Filter
        if self.filter_mode == "gray":
            img = img.convert('L').convert('RGB')
        elif self.filter_mode == "blur":
            img = img.filter(ImageFilter.GaussianBlur(2))
        elif self.filter_mode == "sharpen":
            img = img.filter(ImageFilter.SHARPEN)
        elif self.filter_mode == "edges":
            img = img.filter(ImageFilter.FIND_EDGES).convert('RGB')
        elif self.filter_mode == "threshold":
            img = img.convert('L').point(lambda x: 255 if x > 120 else 0).convert('RGB')

        # Spiegeln
        if self.mirror:
            img = img.transpose(Image.FLIP_LEFT_RIGHT)

        return img

    # --------------------------------------------------
    # Hauptmenü  –  3 Buttons nebeneinander
    # --------------------------------------------------
    def show_main_menu(self):
        self.state = "main_menu"
        img  = new_screen()
        draw_header(img, "SmartBin")
        draw = ImageDraw.Draw(img)
        draw.text((12, HEADER_H + 10), "Muelltrennung", font=FONT_SMALL, fill=C_MUTED)

        BW, BH = 146, 90
        GAP    = 10
        total_w = 3 * BW + 2 * GAP
        ox = (LCD_WIDTH - total_w) // 2
        oy = HEADER_H + 2 + (LCD_HEIGHT - HEADER_H - 2 - BH) // 2 + 8

        buttons = [
            TouchButton(ox,                oy, BW, BH, "Foto aufnehmen", bg=C_PRIMARY),
            TouchButton(ox + BW + GAP,     oy, BW, BH, "Statistiken",    bg=C_SUCCESS),
            TouchButton(ox + 2*(BW + GAP), oy, BW, BH, "Einstellungen",  bg=C_MUTED),
            TouchButton(ox, oy + BH + GAP, total_w, 42, "Beenden",       bg=C_DANGER),
        ]
        for btn in buttons:
            btn.draw(img)
        self.lcd.show_image(img)

        idx = self._wait_for_buttons(buttons)
        if idx == 0:
            self.show_camera_view()
        elif idx == 1:
            self.show_stats()
        elif idx == 2:
            self.show_settings()
        elif idx == 3:
            raise KeyboardInterrupt()

    # --------------------------------------------------
    # Kamera  –  MJPEG-Livestream via rpicam-vid
    # --------------------------------------------------
    def show_camera_view(self):
        self.state  = "camera"
        PREVIEW_H   = LCD_HEIGHT - 50
        BAR_Y       = PREVIEW_H

        back_btn    = TouchButton(8,   BAR_Y + 4, 130, 42, "Zurueck",   bg=C_MUTED)
        capture_btn = TouchButton(146, BAR_Y + 4, 326, 42, "Aufnehmen", bg=C_DANGER)

        frame_queue = queue.Queue(maxsize=2)
        proc = subprocess.Popen(
            ['rpicam-vid', '-t', '0', '--codec', 'mjpeg', '-o', '-',
             '--width', str(LCD_WIDTH), '--height', str(PREVIEW_H),
             '-n', '--framerate', '15'],
            stdout=subprocess.PIPE, stderr=subprocess.DEVNULL
        )

        def _reader():
            buf = b''
            while True:
                chunk = proc.stdout.read(8192)
                if not chunk:
                    break
                buf += chunk
                while True:
                    start = buf.find(b'\xff\xd8')
                    end   = buf.find(b'\xff\xd9', start + 2) if start != -1 else -1
                    if start != -1 and end != -1:
                        jpeg = buf[start:end + 2]
                        buf  = buf[end + 2:]
                        try:
                            frame = Image.open(io.BytesIO(jpeg))
                            frame.load()
                            if frame_queue.full():
                                try: frame_queue.get_nowait()
                                except queue.Empty: pass
                            frame_queue.put_nowait(frame)
                        except Exception:
                            pass
                    else:
                        break

        threading.Thread(target=_reader, daemon=True).start()

        current    = None
        proc_alive = True
        try:
            while self.state == "camera":
                if not self.freeze:
                    try:
                        current = frame_queue.get(timeout=0.05)
                    except queue.Empty:
                        pass
                else:
                    time.sleep(0.05)

                if current is not None:
                    processed = self._apply_settings(current.resize((LCD_WIDTH, PREVIEW_H)))
                    img = new_screen()
                    img.paste(processed, (0, 0))
                    draw = ImageDraw.Draw(img)
                    draw.rectangle([0, PREVIEW_H, LCD_WIDTH, LCD_HEIGHT], fill=C_SURFACE)
                    back_btn.draw(img)
                    capture_btn.draw(img)
                    self.lcd.show_image(img)

                xy = self._get_touch()
                if xy:
                    if back_btn.is_touched(*xy):
                        break
                    if capture_btn.is_touched(*xy):
                        self._show_flash()
                        proc.terminate()
                        proc_alive = False
                        try: proc.wait(timeout=3)
                        except subprocess.TimeoutExpired: proc.kill()
                        capture_rpicam(self.captured_path, width=1920,
                                       height=1080, timeout_ms=1500)
                        self.show_review_screen()
                        return
        finally:
            if proc_alive:
                proc.terminate()
                try: proc.wait(timeout=3)
                except subprocess.TimeoutExpired: proc.kill()

    def _show_flash(self):
        """Kurzes weißes Aufleuchten als Auslöser-Feedback"""
        img = new_screen(C_WHITE)
        self.lcd.show_image(img)
        time.sleep(0.12)

    # --------------------------------------------------
    # Review  –  Foto links, Buttons rechts
    # --------------------------------------------------
    def show_review_screen(self):
        self.state = "review"
        if not self.captured_path.exists():
            self.show_main_menu()
            return

        img = new_screen()
        draw_header(img, "Foto pruefen")

        PHOTO_W = 280
        photo_h = LCD_HEIGHT - HEADER_H - 2
        photo   = Image.open(self.captured_path).resize((PHOTO_W, photo_h))
        img.paste(photo, (0, HEADER_H + 2))

        BX = PHOTO_W + 10
        BW = LCD_WIDTH - BX - 8

        cat_btn  = TouchButton(BX, HEADER_H + 18,  BW, 68, "Kategorie", bg=C_PRIMARY)
        back_btn = TouchButton(BX, HEADER_H + 100, BW, 58, "Zurueck",   bg=C_MUTED)
        cat_btn.draw(img)
        back_btn.draw(img)
        self.lcd.show_image(img)

        idx = self._wait_for_buttons([cat_btn, back_btn])
        if idx == 0:
            self.show_category_menu()
        else:
            self.show_camera_view()

    # --------------------------------------------------
    # Kategorie-Menü  –  3×3 Grid
    # --------------------------------------------------
    def show_category_menu(self):
        self.state = "category_menu"
        img = new_screen()
        draw_header(img, "Kategorie")

        BACK_H    = 44
        content_h = LCD_HEIGHT - HEADER_H - 2 - BACK_H - 6
        BW = (LCD_WIDTH - 4 * 8) // 3
        BH = (content_h - 2 * 6) // 3
        OX = 8
        OY = HEADER_H + 8

        buttons = []
        for i, (name, _) in enumerate(LABELS):
            col, row = i % 3, i // 3
            x = OX + col * (BW + 8)
            y = OY + row * (BH + 6)
            buttons.append(TouchButton(x, y, BW, BH, name, bg=C_PRIMARY, font=FONT_SMALL))

        for btn in buttons:
            btn.draw(img)

        back_btn = TouchButton(8, LCD_HEIGHT - BACK_H - 2, LCD_WIDTH - 16, BACK_H - 4,
                               "Zurueck", bg=C_MUTED)
        back_btn.draw(img)
        self.lcd.show_image(img)

        all_btns = buttons + [back_btn]
        idx = self._wait_for_buttons(all_btns)
        if idx == len(LABELS):
            self.show_review_screen()
        else:
            self.selected_idx = idx
            self.save_photo()

    # --------------------------------------------------
    # Foto speichern  –  mit Bestätigungs-Screen
    # --------------------------------------------------
    def save_photo(self):
        if not self.captured_path.exists() or self.selected_idx is None:
            self.show_main_menu()
            return

        label_name, label_id = LABELS[self.selected_idx]
        timestamp = datetime.now().strftime("%Y%m%d_%H%M%S")
        dest = DATA_DIR / label_id / f"{label_id}_{timestamp}.jpg"
        # HD-Original direkt kopieren (keine Neukompression durch PIL-resize)
        shutil.copy2(self.captured_path, dest)
        print(f"Gespeichert (HD): {dest}")

        img  = new_screen()
        draw = ImageDraw.Draw(img)
        cx, cy = LCD_WIDTH // 2, LCD_HEIGHT // 2 - 28
        r = 52
        draw.ellipse([cx - r, cy - r, cx + r, cy + r], fill=C_SUCCESS)
        draw.text((cx - 20, cy - 16), "OK", font=FONT_LARGE, fill=C_WHITE)

        bb = draw.textbbox((0, 0), label_name, font=FONT_LARGE)
        draw.text(((LCD_WIDTH - (bb[2]-bb[0])) // 2, cy + r + 8),
                  label_name, font=FONT_LARGE, fill=C_WHITE)

        bb2 = draw.textbbox((0, 0), "gespeichert", font=FONT_MEDIUM)
        draw.text(((LCD_WIDTH - (bb2[2]-bb2[0])) // 2, cy + r + 40),
                  "gespeichert", font=FONT_MEDIUM, fill=C_MUTED)
        self.lcd.show_image(img)
        time.sleep(2)

        self.selected_idx = None
        self.show_main_menu()

    # --------------------------------------------------
    # Statistiken  –  2-spaltig mit Balkendiagramm
    # --------------------------------------------------
    def show_stats(self):
        self.state = "stats"
        img  = new_screen()
        draw_header(img, "Statistiken")
        draw = ImageDraw.Draw(img)

        counts = [(name, lid, len(list((DATA_DIR / lid).glob("*.jpg"))))
                  for name, lid in LABELS]
        total  = sum(c for _, _, c in counts)
        max_c  = max(c for _, _, c in counts) or 1

        COL_W   = (LCD_WIDTH - 24) // 2
        BAR_MAX = COL_W - 90
        y0      = HEADER_H + 8
        ROW_H   = 26

        for i, (name, _, count) in enumerate(counts):
            col = i % 2
            row = i // 2
            x  = 8 + col * (COL_W + 8)
            ry = y0 + row * ROW_H
            bar_w = max(4, int(BAR_MAX * count / max_c))
            draw_rounded_rect(draw, x, ry, bar_w + 80, 22, 5, C_PRIMARY)
            draw.text((x + 4, ry + 4), f"{name}: {count}", font=FONT_SMALL, fill=C_WHITE)

        sep_y = y0 + 5 * ROW_H
        draw.rectangle([8, sep_y, LCD_WIDTH - 8, sep_y + 1], fill=C_MUTED)
        draw.text((8, sep_y + 5), f"Gesamt: {total}", font=FONT_MEDIUM, fill=C_WHITE)

        back_btn = TouchButton(8, LCD_HEIGHT - 48, LCD_WIDTH - 16, 40, "Zurueck", bg=C_MUTED)
        back_btn.draw(img)
        self.lcd.show_image(img)
        self._wait_for_buttons([back_btn])
        self.show_main_menu()

    # --------------------------------------------------
    # Einstellungen  –  vollständig
    # --------------------------------------------------
    def show_settings(self):
        self.state = "settings"

        FILTERS = [
            ("Normal",        "normal"),
            ("Grau",          "gray"),
            ("Weichzeichnen", "blur"),
            ("Schaerfen",     "sharpen"),
            ("Kanten",        "edges"),
            ("Threshold",     "threshold"),
        ]
        filt_names  = [f[0] for f in FILTERS]
        filt_values = [f[1] for f in FILTERS]
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

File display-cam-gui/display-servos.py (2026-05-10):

#!/usr/bin/python
# -*- coding: UTF-8 -*-

import sys
import time
from gpiozero import Servo
from PIL import Image, ImageDraw, ImageFont

import ft6336u
import st7796

# ========================================
# Display / UI config
# ========================================

LCD_WIDTH = 480
LCD_HEIGHT = 320
HEADER_H = 46
TOUCH_TIMEOUT = 0.05

FONT_PATH = "/usr/share/fonts/truetype/dejavu/DejaVuSans.ttf"
FONT_PATH_BOLD = "/usr/share/fonts/truetype/dejavu/DejaVuSans-Bold.ttf"
FONT_LARGE = ImageFont.truetype(FONT_PATH_BOLD, 24)
FONT_MEDIUM = ImageFont.truetype(FONT_PATH, 18)
FONT_SMALL = ImageFont.truetype(FONT_PATH, 13)

C_BG = (18, 18, 18)
C_SURFACE = (35, 35, 45)
C_PRIMARY = (41, 98, 255)
C_SUCCESS = (30, 190, 90)
C_DANGER = (220, 50, 50)
C_MUTED = (120, 120, 135)
C_WHITE = (255, 255, 255)
C_HEADER = (25, 25, 40)

# ========================================
# Servo config
# ========================================

servos = {
    "horizontal": Servo(16),
    "vertical": Servo(20),
}

directions = {
    "rf": {"horizontal": "min", "vertical": "min"},
    "lf": {"horizontal": "max", "vertical": "min"},
    "lb": {"horizontal": "min", "vertical": "max"},
    "rb": {"horizontal": "max", "vertical": "max"},
}

# ========================================
# UI helpers
# ========================================

def new_screen(bg=C_BG):
    return Image.new("RGB", (LCD_WIDTH, LCD_HEIGHT), color=bg)

def draw_header(image, title):
    draw = ImageDraw.Draw(image)
    draw.rectangle([0, 0, LCD_WIDTH, HEADER_H], fill=C_HEADER)
    draw.rectangle([0, HEADER_H, LCD_WIDTH, HEADER_H + 2], fill=C_PRIMARY)
    bbox = draw.textbbox((0, 0), title, font=FONT_LARGE)
    tx = (LCD_WIDTH - (bbox[2] - bbox[0])) // 2
    ty = (HEADER_H - (bbox[3] - bbox[1])) // 2
    draw.text((tx, ty), title, font=FONT_LARGE, fill=C_WHITE)

def draw_rounded_rect(draw, x, y, w, h, radius, fill):
    draw.rectangle([x + radius, y, x + w - radius, y + h], fill=fill)
    draw.rectangle([x, y + radius, x + w, y + h - radius], fill=fill)
    draw.ellipse([x, y, x + 2 * radius, y + 2 * radius], fill=fill)
    draw.ellipse([x + w - 2 * radius, y, x + w, y + 2 * radius], fill=fill)
    draw.ellipse([x, y + h - 2 * radius, x + 2 * radius, y + h], fill=fill)
    draw.ellipse([x + w - 2 * radius, y + h - 2 * radius, x + w, y + h], fill=fill)

class TouchButton:
    def __init__(self, x, y, w, h, text, bg=C_PRIMARY, fg=C_WHITE, font=None, radius=10):
        self.x, self.y, self.w, self.h = x, y, w, h
        self.text = text
        self.bg = bg
        self.fg = fg
        self.font = font or FONT_MEDIUM
        self.radius = radius

    def is_touched(self, tx, ty):
        return self.x <= tx <= self.x + self.w and self.y <= ty <= self.y + self.h

    def draw(self, image):
        draw = ImageDraw.Draw(image)
        draw_rounded_rect(draw, self.x, self.y, self.w, self.h, self.radius, self.bg)
        bbox = draw.textbbox((0, 0), self.text, font=self.font)
        tw = bbox[2] - bbox[0]
        th = bbox[3] - bbox[1]
        draw.text((self.x + (self.w - tw) // 2, self.y + (self.h - th) // 2), self.text, font=self.font, fill=self.fg)

# ========================================
# Servo display app
# ========================================

class ServoDisplayApp:
    def __init__(self):
        print("Initialisiere Servo Display...")
        try:
            self.lcd = st7796.st7796()
            self.touch = ft6336u.ft6336u()
        except Exception as e:
            print(f"Hardware-Fehler: {e}")
            sys.exit(1)

        self.status = "Ready"
        self.state = "main_menu"
        self.lcd.clear()
        self.center_all()

    def _get_touch(self):
        self.touch.read_touch_data()
        result = self.touch.get_touch_xy()
        if result is None:
            return None
        point, coords = result
        if point != 0 and coords:
            px = coords[0]["x"]
            py = coords[0]["y"]
            lx = 479 - py
            ly = 319 - px
            return lx, ly
        return None

    def _wait_for_buttons(self, buttons):
        while True:
            xy = self._get_touch()
            if xy:
                for i, btn in enumerate(buttons):
                    if btn.is_touched(*xy):
                        time.sleep(0.12)
                        return i
            time.sleep(TOUCH_TIMEOUT)

    def center_all(self):
        for servo in servos.values():
            servo.mid()
        self.status = "All servos centered"
        time.sleep(0.2)

    def move_direction(self, key):
        mapping = directions.get(key)
        if not mapping:
            self.status = "Invalid direction"
            return

        for servo_name, position in mapping.items():
            getattr(servos[servo_name], position)()
            time.sleep(0.7)

        time.sleep(1.0)
        servos["vertical"].mid()
        time.sleep(0.7)
        servos["horizontal"].mid()
        time.sleep(0.7)
        self.status = f"Direction {key} done"

    def move_single(self, servo_name, position):
        getattr(servos[servo_name], position)()
        self.status = f"{servo_name} -> {position}"
        time.sleep(0.15)

    def _draw_footer_status(self, img):
        draw = ImageDraw.Draw(img)
        draw.rectangle([0, LCD_HEIGHT - 28, LCD_WIDTH, LCD_HEIGHT], fill=C_SURFACE)
        draw.text((8, LCD_HEIGHT - 22), self.status, font=FONT_SMALL, fill=C_WHITE)

    def show_main_menu(self):
        self.state = "main_menu"
        img = new_screen()
        draw_header(img, "Servo Control")

        title = ImageDraw.Draw(img)
        title.text((12, HEADER_H + 10), "Choose control mode", font=FONT_SMALL, fill=C_MUTED)

        buttons = [
            TouchButton(40, 90, 400, 64, "Direction Control", bg=C_PRIMARY),
            TouchButton(40, 170, 400, 64, "Individual Servo", bg=C_SUCCESS),
            TouchButton(40, 250, 195, 42, "Center All", bg=C_MUTED),
            TouchButton(245, 250, 195, 42, "Exit", bg=C_DANGER),
        ]
        for btn in buttons:
            btn.draw(img)
        self._draw_footer_status(img)
        self.lcd.show_image(img)

        idx = self._wait_for_buttons(buttons)
        if idx == 0:
            self.show_direction_menu()
        elif idx == 1:
            self.show_individual_menu()
        elif idx == 2:
            self.center_all()
        elif idx == 3:
            raise KeyboardInterrupt()

    def show_direction_menu(self):
        self.state = "direction_menu"
        while True:
            img = new_screen()
            draw_header(img, "Direction Input")
            draw = ImageDraw.Draw(img)
            draw.text((12, HEADER_H + 8), "Like direction-input.py: lf / rf / lb / rb", font=FONT_SMALL, fill=C_MUTED)
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

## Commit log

2026-05-06 servo pushrod assembly
    [Servo-assembly.FCStd]
2026-05-06 longer middle pushrod for elastic bands as locks
    [bin-Middle-pushrod.3mf, bin-base-multipart.FCStd]
2026-05-06 plate locker for elastic bands
    [bin-base-multipart.FCStd, bin-pushrod-plate-locker.3mf]
2026-05-07 added exit button to main.py & created dashboard.py
2026-05-10 fixed busy gpio pins
    [dashboard.py, display-servos.py, ft6336u.py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]
2026-05-10 display driver backlight change
2026-05-10 display driver fix
2026-06-30 Remove large file
    [Pi Camera Module v3 Wide Angle.STL, Raspberry Pi 4 Model B.stl, Standard-Servo.stl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]
2026-06-30 adjusted servos placement
2026-09-11 gitignore für runs und modells gelöscht
    [results.csv]
2026-09-14 blender base model
    materials + animation + scene still missing
    [Raspberry Pi 4 Model B.stl, bin-End-pushrod.stl, bin-Middle-pushrod.stl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]
2026-10-05 New Run with new dataset and added support for multi-class detection
    [results.csv]
2026-10-09 rigged bin
    [bin-middle-pushrod.3mf]
2026-10-20 print in place pushrod
2026-11-10 rpi led test code
2026-11-10 LED Bluetooth frame
2026-11-10 LED BT code
2026-11-10 esp32 code
